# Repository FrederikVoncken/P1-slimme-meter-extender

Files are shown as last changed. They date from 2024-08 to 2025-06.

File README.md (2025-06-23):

# P1-slimme-meter-extender
Extending the range for a P1 slimmer meter connection and even making it possible to connect multiple receivers (having their own data enable).
***
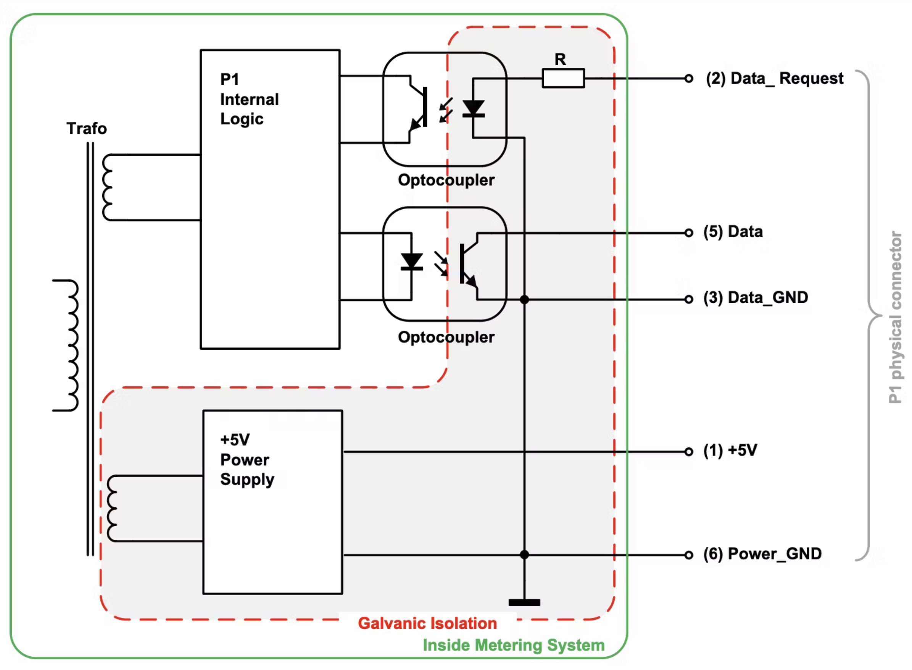
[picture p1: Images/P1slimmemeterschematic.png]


The inside of the P1 communication part.

See also 
[Wiki P1-poort](https://nl.wikipedia.org/wiki/P1-poort) and [DSMR P1 Companion Standard 5.0.2](https://www.netbeheernederland.nl/publicatie/dsmr-502-p1-companion-standard)
***
The schematic shows the extension of the Smartmeter P1 port to
* 2 (isolated) P1 outputs
* 2 P1 output extenders (RS485) to multiple meters
* Multiple options for isolation and power

See also the Kicad directory for the project and schematic
[Schematic](Kicad/P1SmartMeter.pdf)

The schematic can be extended to more P1 output or more P1 extenders

Images of the Main part, top and back

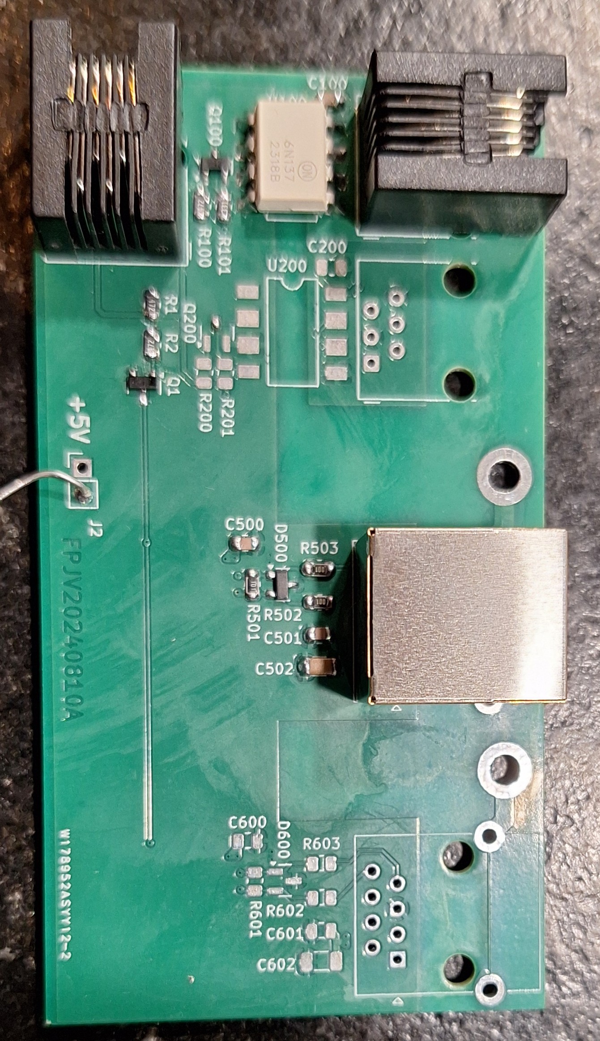
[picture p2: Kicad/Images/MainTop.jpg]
MainTop


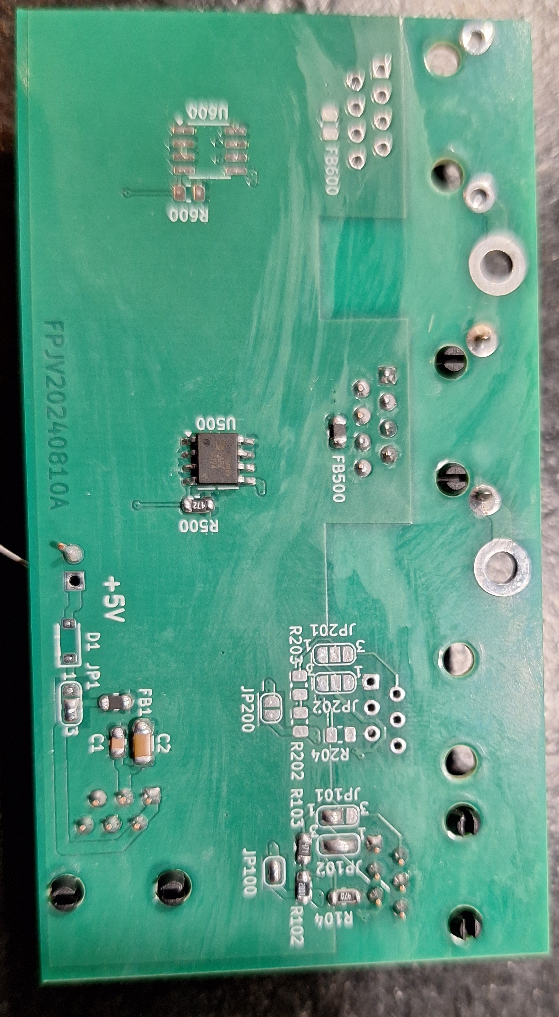
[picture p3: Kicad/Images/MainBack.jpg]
MainBack


Images of the extender receiving part, top and back

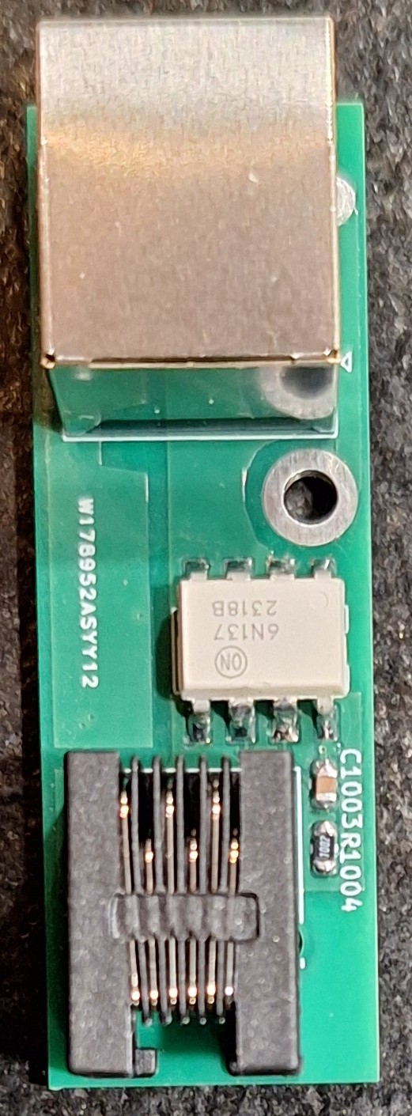
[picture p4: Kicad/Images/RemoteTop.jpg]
RemoteTop


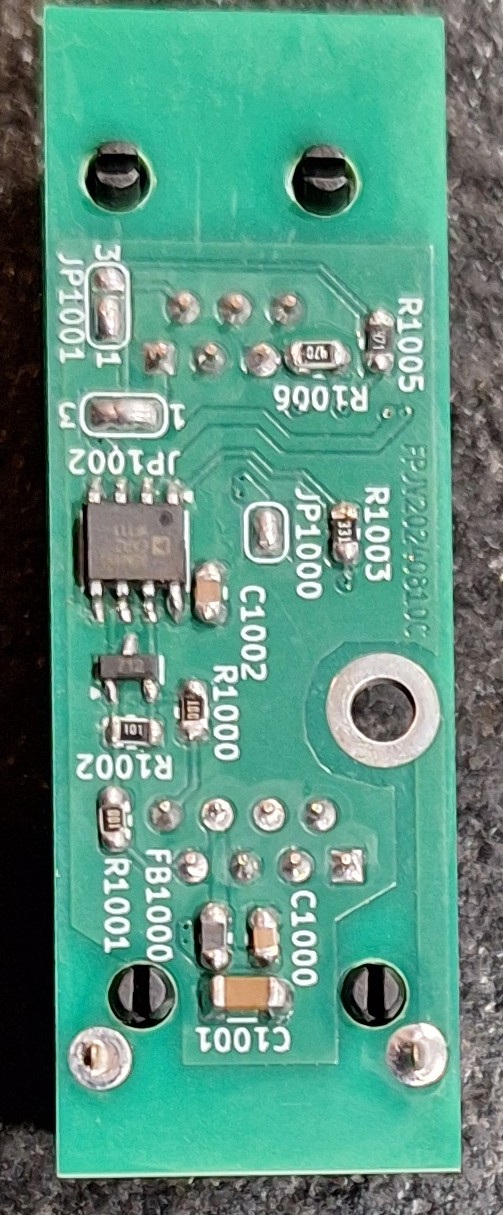
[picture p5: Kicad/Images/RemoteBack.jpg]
RemoteBack


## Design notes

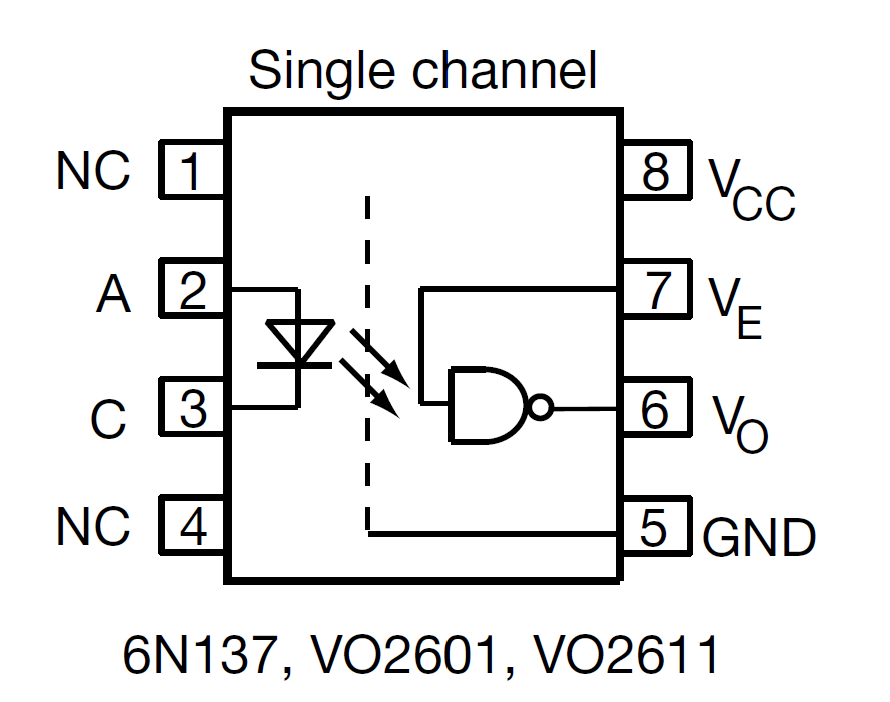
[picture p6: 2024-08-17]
Images/6n137.png

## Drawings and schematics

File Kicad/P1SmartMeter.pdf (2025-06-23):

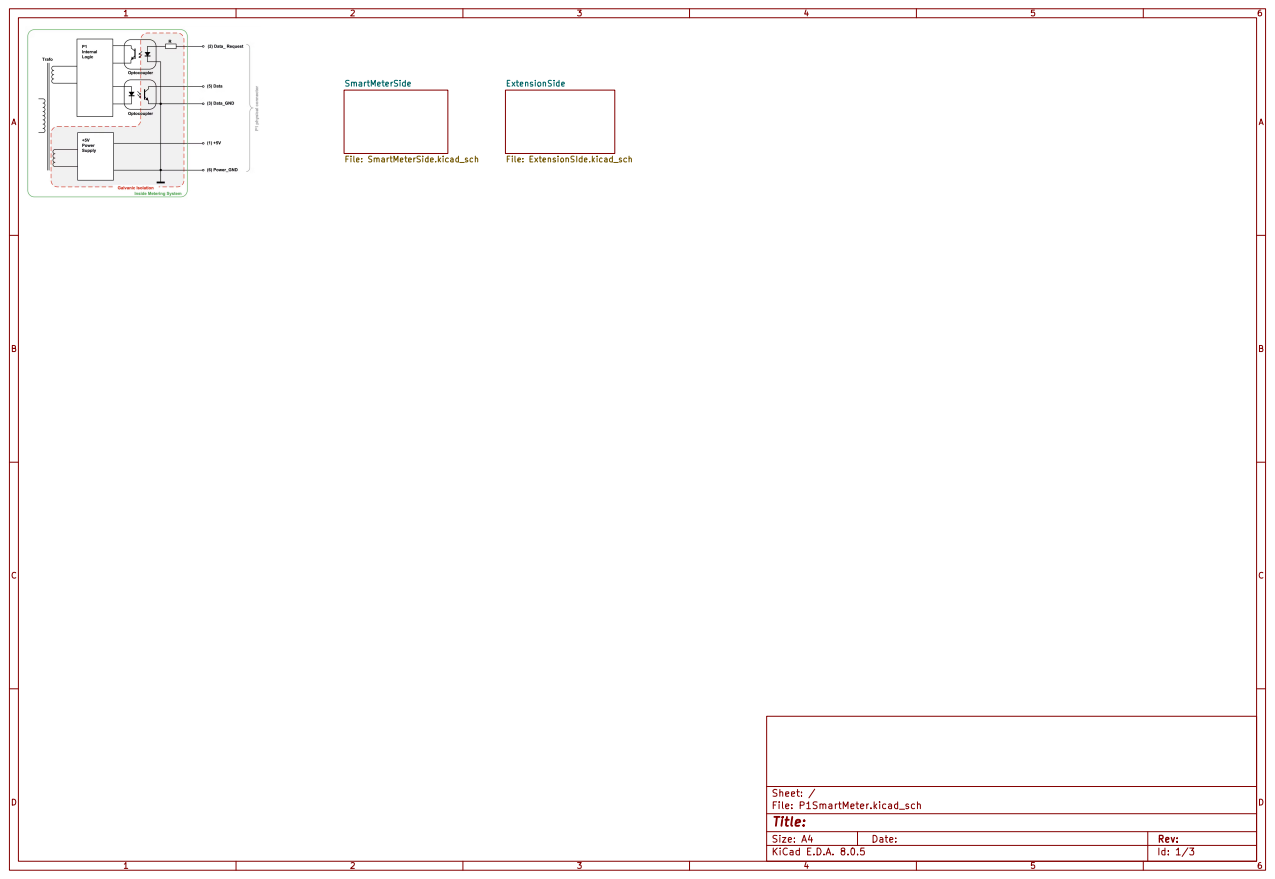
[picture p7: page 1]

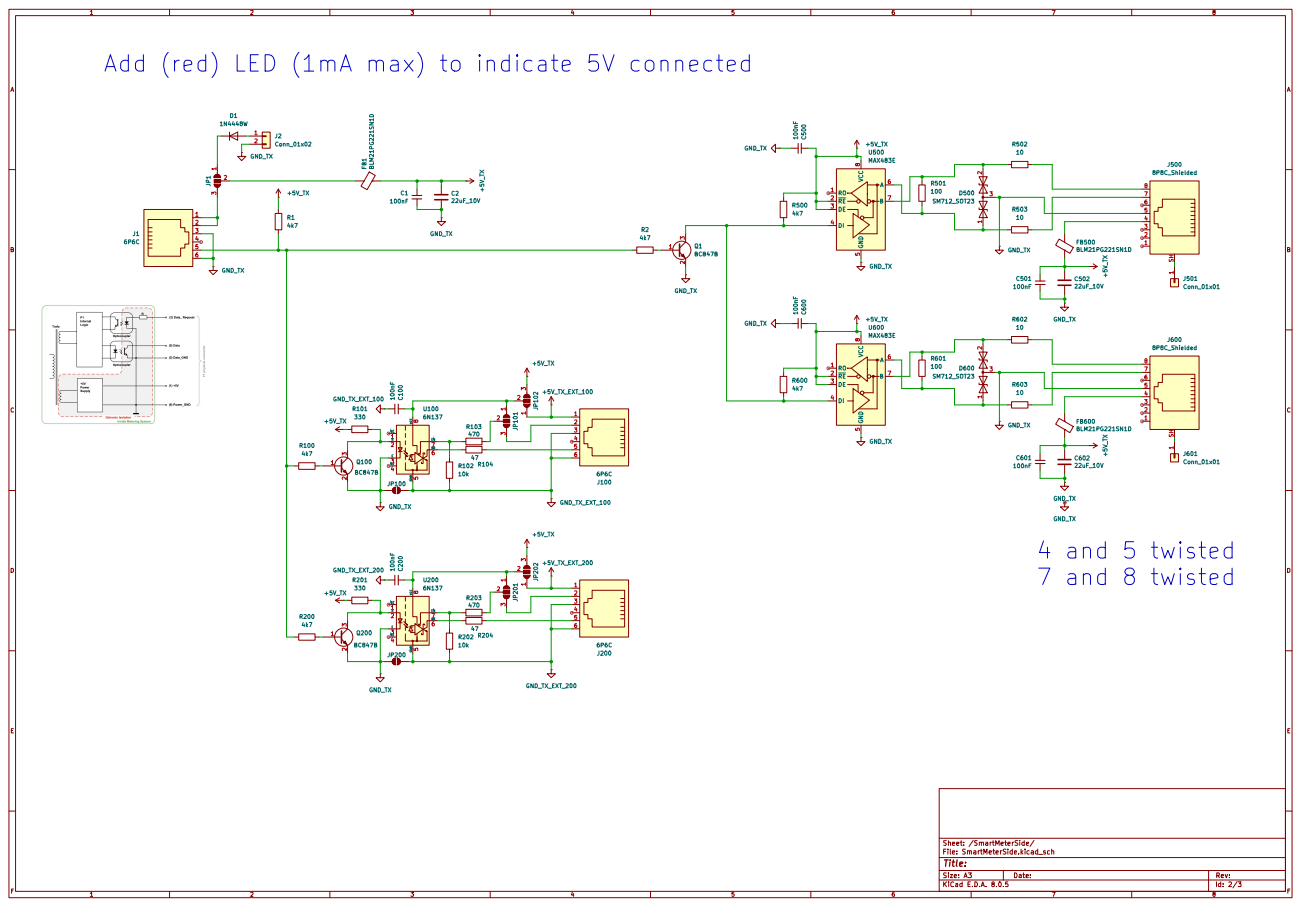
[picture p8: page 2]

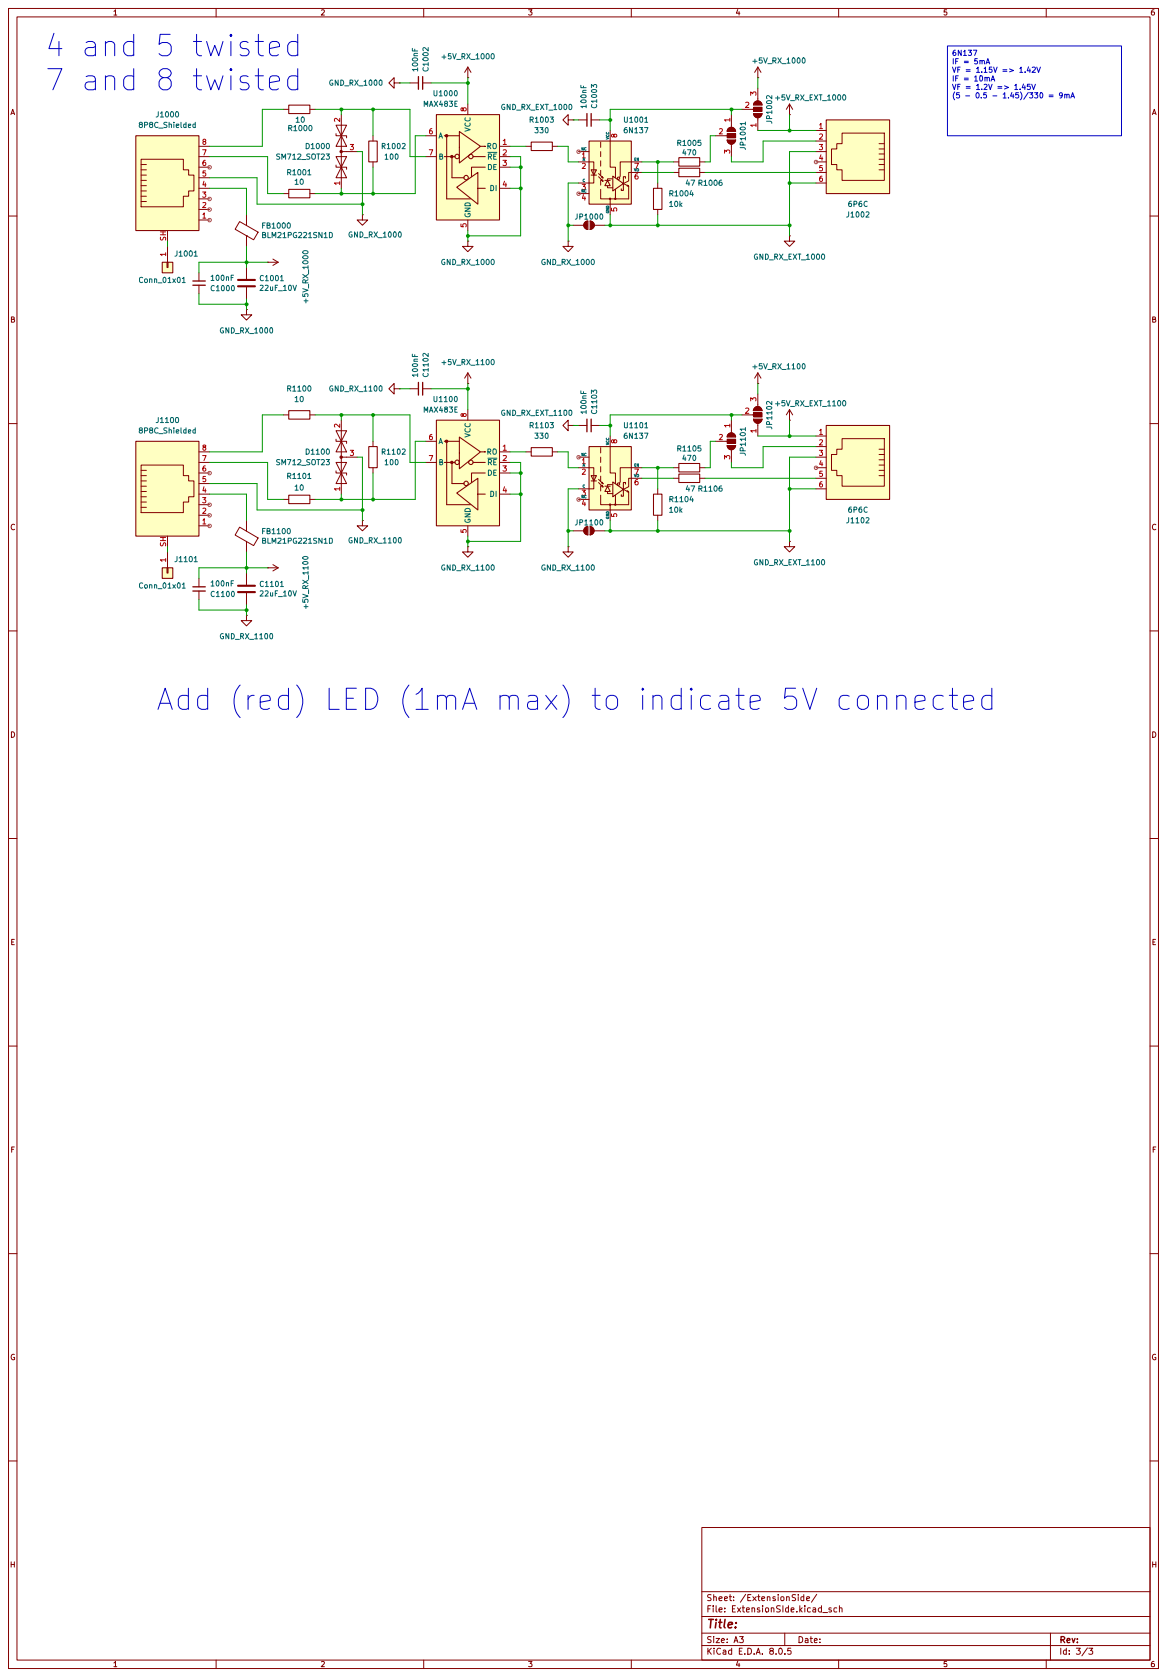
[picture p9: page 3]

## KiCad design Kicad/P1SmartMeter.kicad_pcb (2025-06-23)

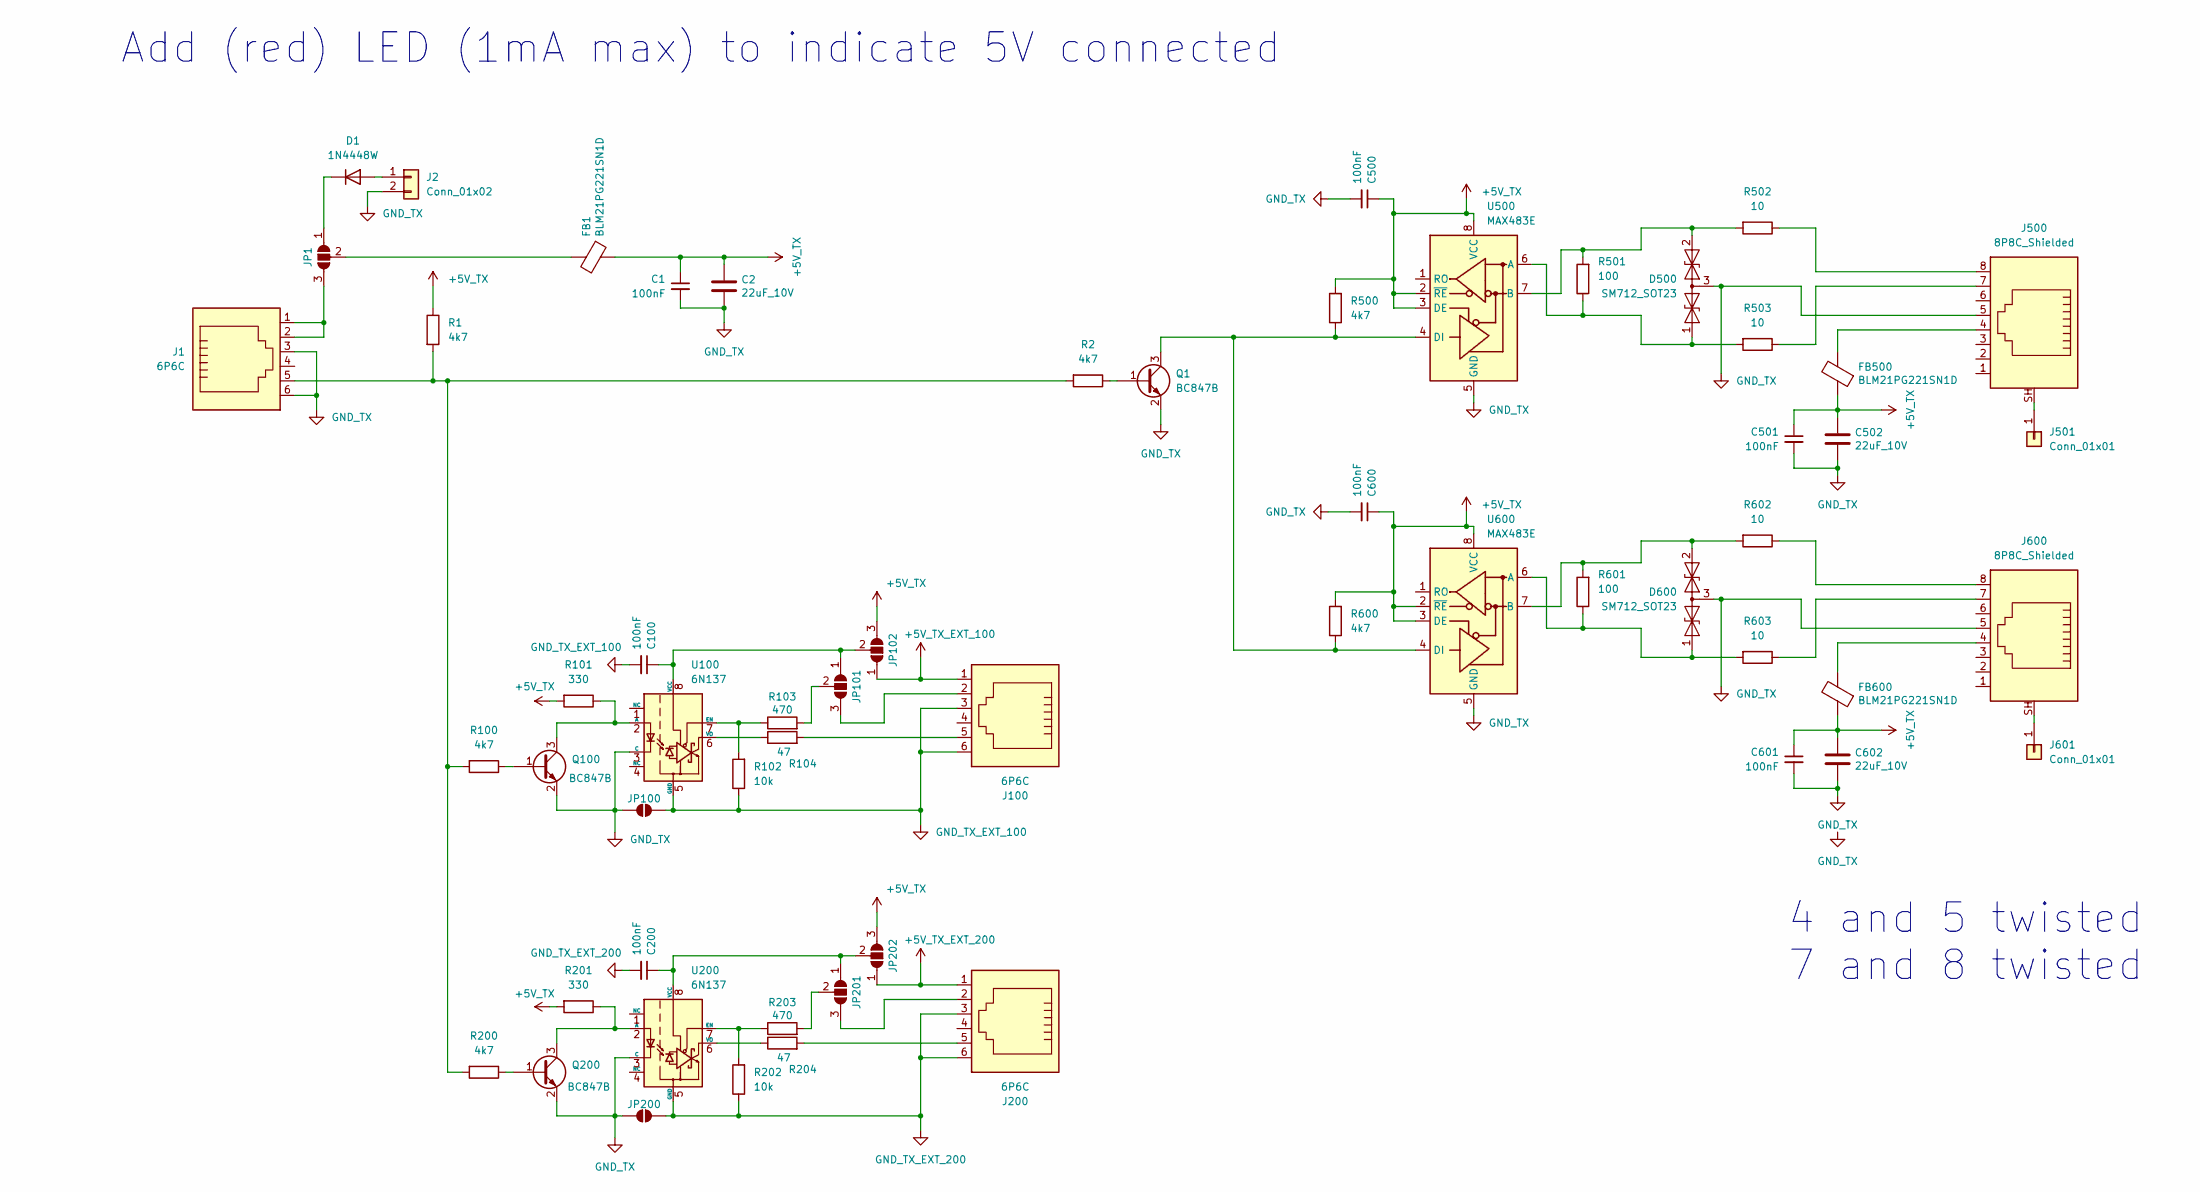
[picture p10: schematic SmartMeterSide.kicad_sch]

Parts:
C1, C100, C200, C500, C501, C600, C601: 100nF; C_0805_2012Metric
C2, C502, C602: 22uF_10V; C_1206_3216Metric
D1: 1N4448W; D_SOD-123
D500, D600: SM712_SOT23; SOT-23
FB1, FB500, FB600: BLM21PG221SN1D; R_0805_2012Metric
J1, J100, J200: 6P6C; RJ12_Amphenol_54601-x06_Horizontal
J2: Conn_01x02; PinHeader_1x02_P2.54mm_Vertical
J500, J600: 8P8C_Shielded; RJ45_Ninigi_GE
J501, J601: Conn_01x01; MountingHole_3.2mm_M3_DIN965_Pad_TopBottom
JP1, JP101, JP102, JP201, JP202: SolderJumper_3_Open; SolderJumper-3_P1.3mm_Open_RoundedPad1.0x1.5mm_NumberLabels
JP100, JP200: SolderJumper_2_Open; SolderJumper-2_P1.3mm_Open_RoundedPad1.0x1.5mm
Q1, Q100, Q200: BC847B; SOT-23
R1, R2, R100, R200, R500, R600: 4k7; R_0805_2012Metric
R101, R201: 330; R_0805_2012Metric
R102, R202: 10k; R_0805_2012Metric
R103, R203: 470; R_0805_2012Metric
R104, R204: 47; R_0805_2012Metric
R501, R601: 100; R_0805_2012Metric
R502, R503, R602, R603: 10; R_0805_2012Metric
U100, U200: 6N137; PowerIntegrations_SMD-8
U500, U600: MAX483E; SOIC-8_3.9x4.9mm_P1.27mm

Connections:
+5V_TX: C1.1, C2.1, C500.1, C501.1, C502.1, C600.1, C601.1, C602.1, FB1.1, FB500.1, FB600.1, JP102.3 (B), JP202.3 (B), R1.1, R101.2, R201.2, R500.2, R600.2, U500.2 (~RE), U500.3 (DE), U500.8 (VCC), U600.2 (~RE), U600.3 (DE), U600.8 (VCC)
+5V_TX_EXT_100: J100.1, JP102.1 (A)
+5V_TX_EXT_200: J200.1, JP202.1 (A)
GND_TX: C1.2, C2.2, C500.2, C501.2, C502.2, C600.2, C601.2, C602.2, D500.3 (common), D600.3 (common), J1.3, J1.6, J2.2, J500.5, J600.5, JP100.1 (A), JP200.1 (A), Q1.2 (E), Q100.2 (E), Q200.2 (E), U100.3 (C), U200.3 (C), U500.5 (GND), U600.5 (GND)
GND_TX_EXT_100: C100.2, J100.3, J100.6, JP100.2 (B), R102.1, U100.5 (GND)
GND_TX_EXT_200: C200.2, J200.3, J200.6, JP200.2 (B), R202.1, U200.5 (GND)
unnamed: D1.2 (A), J2.1
unnamed: D1.1 (K), JP1.1 (A)
unnamed: D500.1 (A1), R501.1, R503.2, U500.6 (A)
unnamed: D500.2 (A2), R501.2, R502.2, U500.7 (B)
unnamed: D600.1 (A1), R601.1, R603.2, U600.6 (A)
unnamed: D600.2 (A2), R601.2, R602.2, U600.7 (B)
unnamed: FB500.2, J500.4
unnamed: FB600.2, J600.4
unnamed: J1.5, R1.2, R2.2, R100.2, R200.2
unnamed: J100.5, R104.2
unnamed: J200.5, R204.2
unnamed: J500.7, R503.1
unnamed: J500.8, R502.1
unnamed: J500.SH, J501.1
unnamed: J600.7, R603.1
unnamed: J600.8, R602.1
unnamed: J600.SH, J601.1
unnamed: J1.1, J1.2, JP1.3 (B)
unnamed: FB1.2, JP1.2 (C)
unnamed: C100.1, JP101.1 (A), JP102.2 (C), U100.8 (VCC)
unnamed: J100.2, JP101.3 (B)
unnamed: JP101.2 (C), R103.2
unnamed: C200.1, JP201.1 (A), JP202.2 (C), U200.8 (VCC)
unnamed: J200.2, JP201.3 (B)
unnamed: JP201.2 (C), R203.2
unnamed: Q1.1 (B), R2.1
unnamed: Q1.3 (C), R500.1, R600.1, U500.4 (DI), U600.4 (DI)
unnamed: Q100.1 (B), R100.1
unnamed: Q100.3 (C), R101.1, U100.2 (A)
unnamed: Q200.1 (B), R200.1
unnamed: Q200.3 (C), R201.1, U200.2 (A)
unnamed: R102.2, R103.1, U100.7 (EN)
unnamed: R104.1, U100.6 (VO)
unnamed: R202.2, R203.1, U200.7 (EN)
unnamed: R204.1, U200.6 (VO)

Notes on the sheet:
Add (red) LED (1mA max) to indicate 5V connected
4 and 5 twisted 7 and 8 twisted

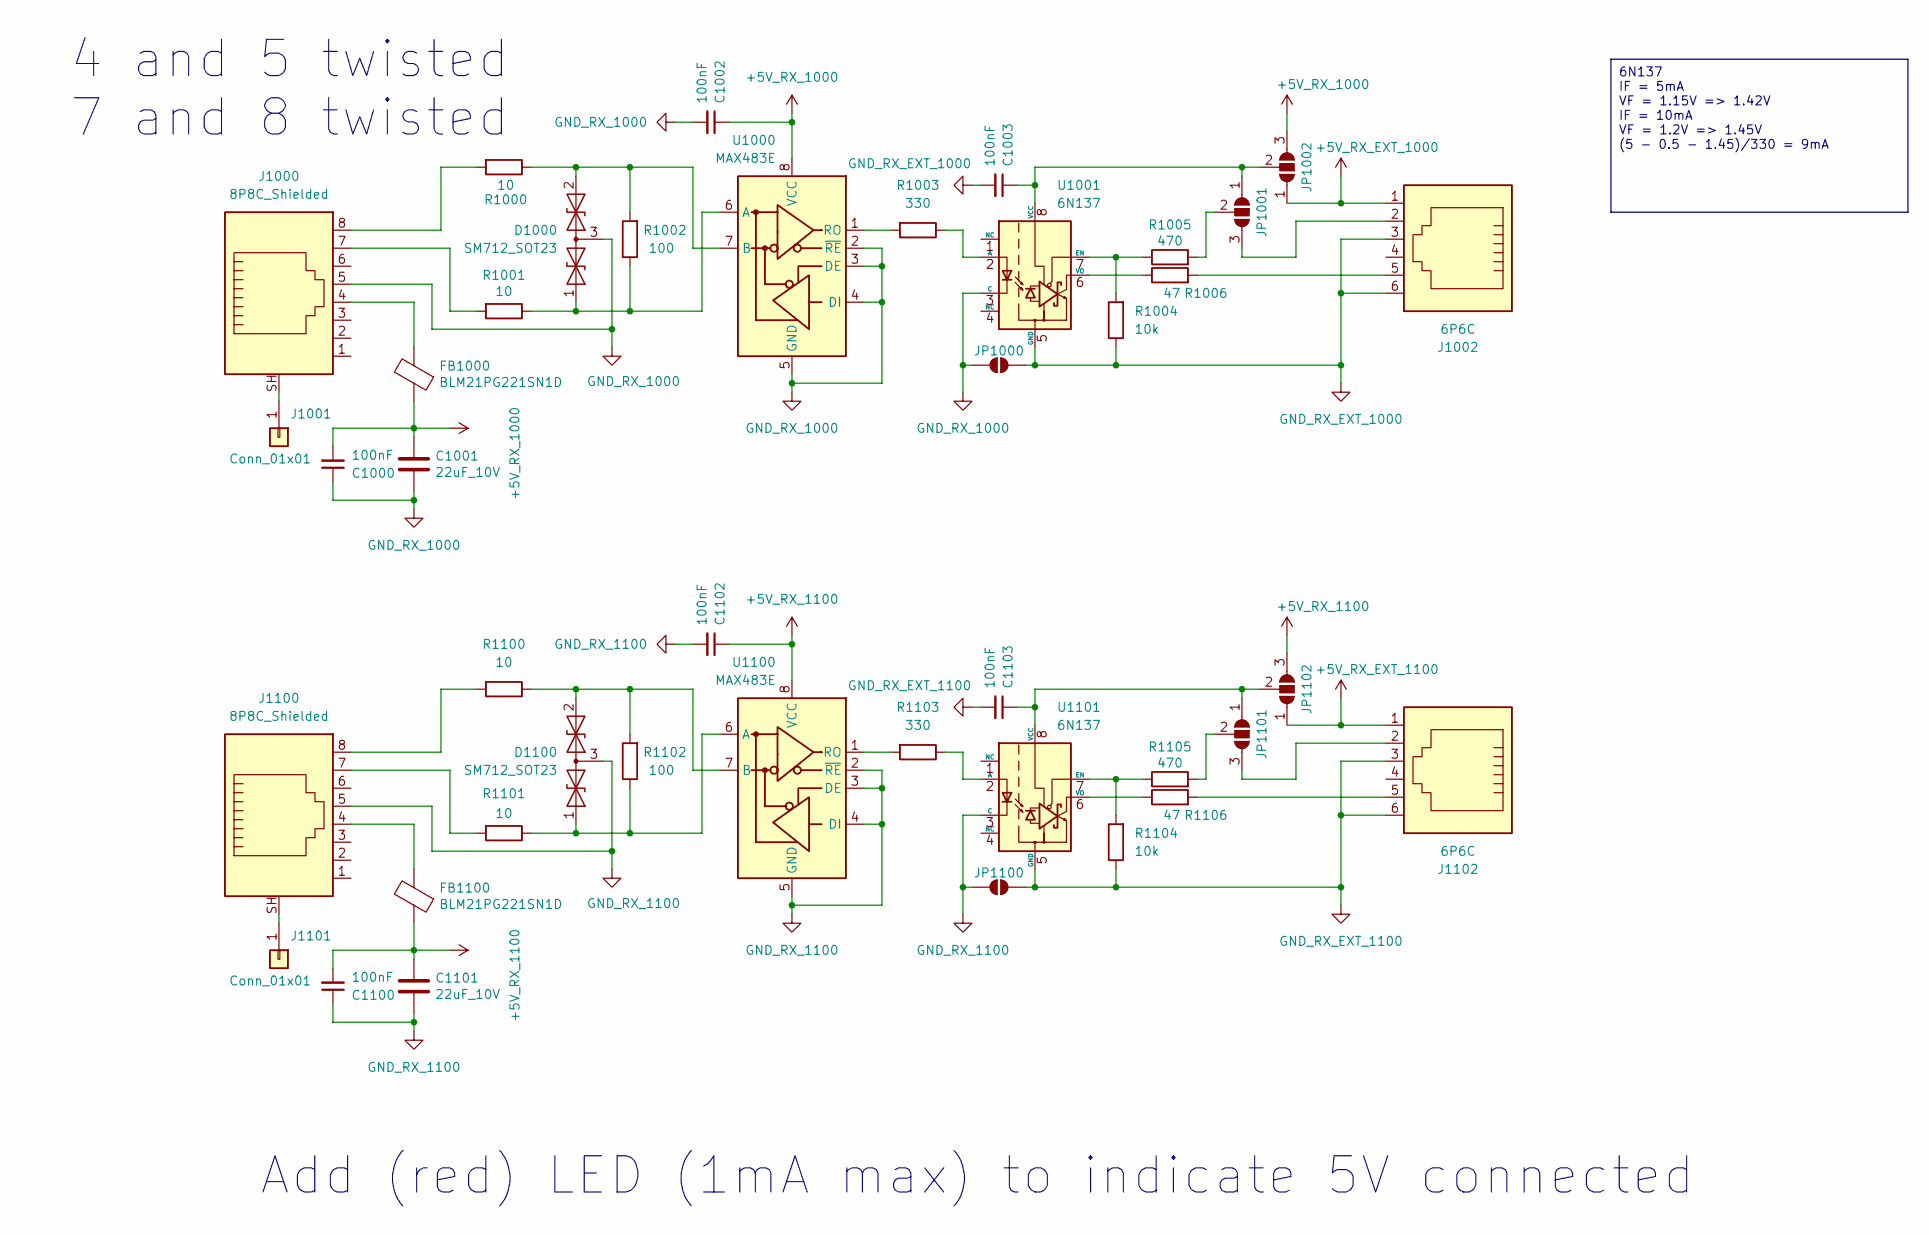
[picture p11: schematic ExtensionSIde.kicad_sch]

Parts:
C1000, C1002, C1003, C1100, C1102, C1103: 100nF; C_0805_2012Metric
C1001, C1101: 22uF_10V; C_1206_3216Metric
D1000, D1100: SM712_SOT23; SOT-23
FB1000, FB1100: BLM21PG221SN1D; R_0805_2012Metric
J1000, J1100: 8P8C_Shielded; RJ45_Ninigi_GE
J1001, J1101: Conn_01x01; MountingHole_3.2mm_M3_DIN965_Pad_TopBottom
J1002, J1102: 6P6C; RJ12_Amphenol_54601-x06_Horizontal
JP1000, JP1100: SolderJumper_2_Open; SolderJumper-2_P1.3mm_Open_RoundedPad1.0x1.5mm
JP1001, JP1002, JP1101, JP1102: SolderJumper_3_Open; SolderJumper-3_P1.3mm_Open_RoundedPad1.0x1.5mm_NumberLabels
R1000, R1001, R1100, R1101: 10; R_0805_2012Metric
R1002, R1102: 100; R_0805_2012Metric
R1003, R1103: 330; R_0805_2012Metric
R1004, R1104: 10k; R_0805_2012Metric
R1005, R1105: 470; R_0805_2012Metric
R1006, R1106: 47; R_0805_2012Metric
U1000, U1100: MAX483E; SOIC-8_3.9x4.9mm_P1.27mm
U1001, U1101: 6N137; PowerIntegrations_SMD-8

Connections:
+5V_RX_1000: C1000.2, C1001.1, C1002.1, FB1000.1, JP1002.3 (B), U1000.8 (VCC)
+5V_RX_1100: C1100.2, C1101.1, C1102.1, FB1100.1, JP1102.3 (B), U1100.8 (VCC)
+5V_RX_EXT_1000: J1002.1, JP1002.1 (A)
+5V_RX_EXT_1100: J1102.1, JP1102.1 (A)
GND_RX_1000: C1000.1, C1001.2, C1002.2, D1000.3 (common), J1000.5, JP1000.1 (A), U1000.2 (~RE), U1000.3 (DE), U1000.4 (DI), U1000.5 (GND), U1001.3 (C)
GND_RX_1100: C1100.1, C1101.2, C1102.2, D1100.3 (common), J1100.5, JP1100.1 (A), U1100.2 (~RE), U1100.3 (DE), U1100.4 (DI), U1100.5 (GND), U1101.3 (C)
GND_RX_EXT_1000: C1003.2, J1002.3, J1002.6, JP1000.2 (B), R1004.1, U1001.5 (GND)
GND_RX_EXT_1100: C1103.2, J1102.3, J1102.6, JP1100.2 (B), R1104.1, U1101.5 (GND)
unnamed: D1000.1 (A1), R1001.1, R1002.1, U1000.6 (A)
unnamed: D1000.2 (A2), R1000.1, R1002.2, U1000.7 (B)
unnamed: D1100.1 (A1), R1101.1, R1102.1, U1100.6 (A)
unnamed: D1100.2 (A2), R1100.1, R1102.2, U1100.7 (B)
unnamed: FB1000.2, J1000.4
unnamed: FB1100.2, J1100.4
unnamed: J1000.7, R1001.2
unnamed: J1000.8, R1000.2
unnamed: J1000.SH, J1001.1
unnamed: J1002.5, R1006.2
unnamed: J1100.7, R1101.2
unnamed: J1100.8, R1100.2
unnamed: J1100.SH, J1101.1
unnamed: J1102.5, R1106.2
unnamed: C1003.1, JP1001.1 (A), JP1002.2 (C), U1001.8 (VCC)
unnamed: J1002.2, JP1001.3 (B)
unnamed: JP1001.2 (C), R1005.2
unnamed: C1103.1, JP1101.1 (A), JP1102.2 (C), U1101.8 (VCC)
unnamed: J1102.2, JP1101.3 (B)
unnamed: JP1101.2 (C), R1105.2
unnamed: R1003.2, U1000.1 (RO)
unnamed: R1003.1, U1001.2 (A)
unnamed: R1004.2, R1005.1, U1001.7 (EN)
unnamed: R1006.1, U1001.6 (VO)
unnamed: R1103.2, U1100.1 (RO)
unnamed: R1103.1, U1101.2 (A)
unnamed: R1104.2, R1105.1, U1101.7 (EN)
unnamed: R1106.1, U1101.6 (VO)

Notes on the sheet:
6N137 IF = 5mA VF = 1.15V => 1.42V IF = 10mA VF = 1.2V => 1.45V (5 - 0.5 - 1.45)/330 = 9mA
4 and 5 twisted 7 and 8 twisted
Add (red) LED (1mA max) to indicate 5V connected

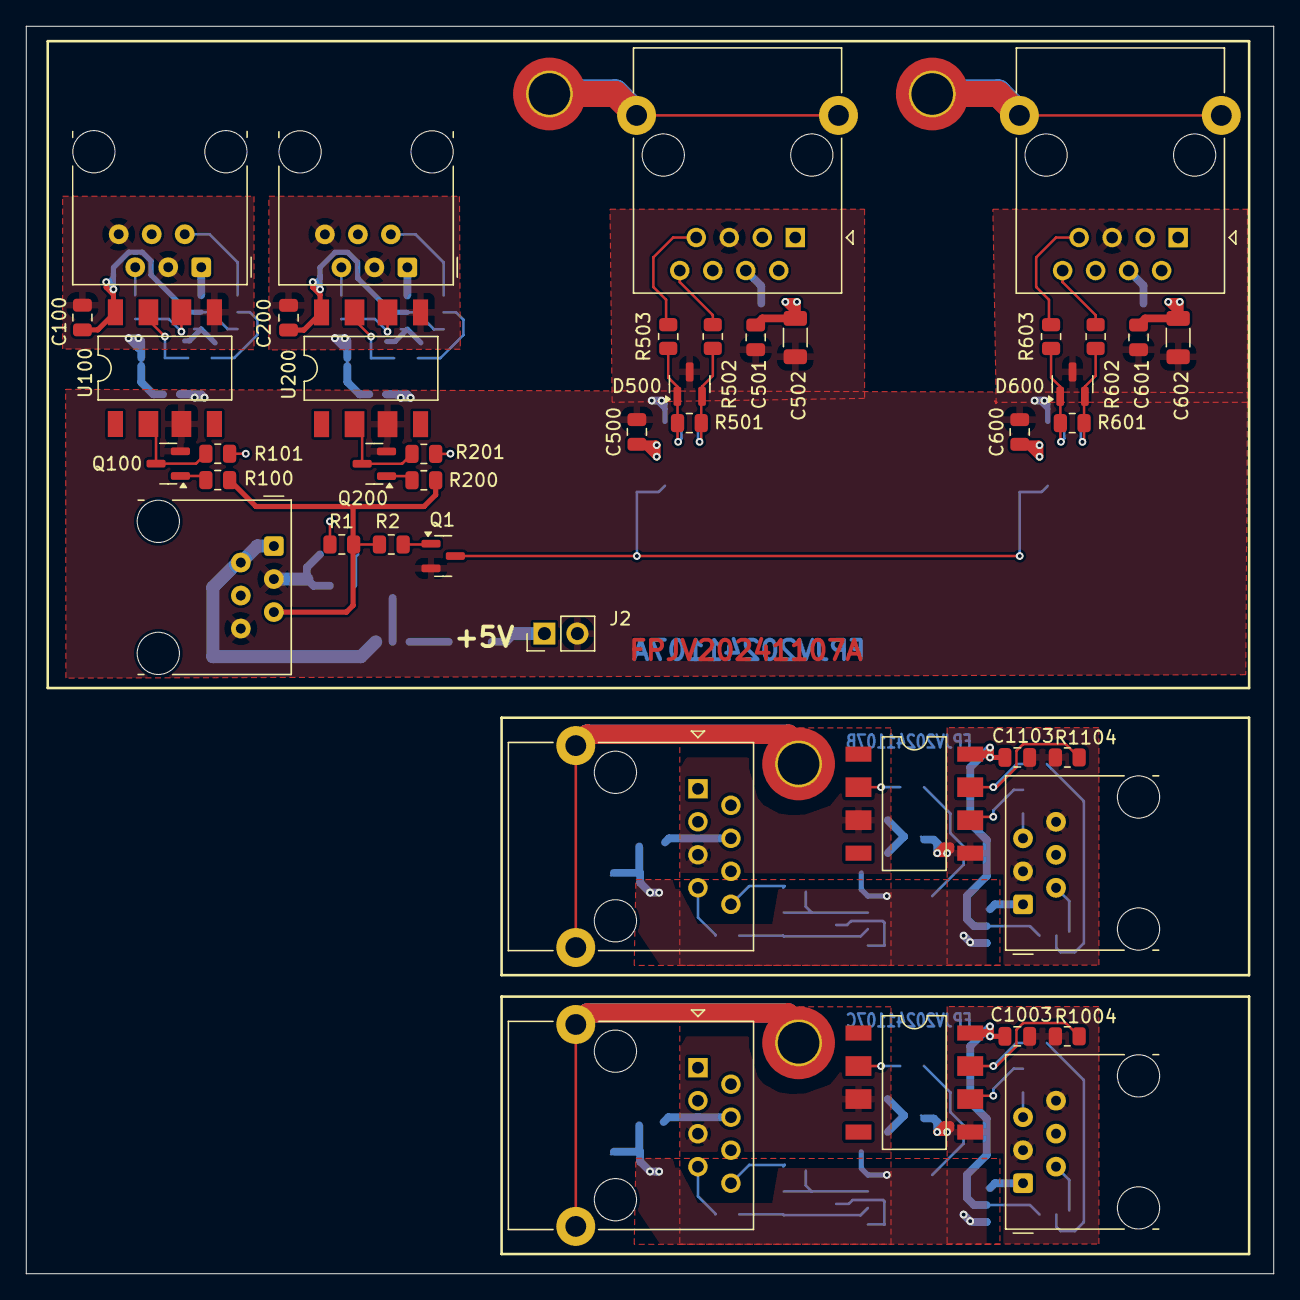
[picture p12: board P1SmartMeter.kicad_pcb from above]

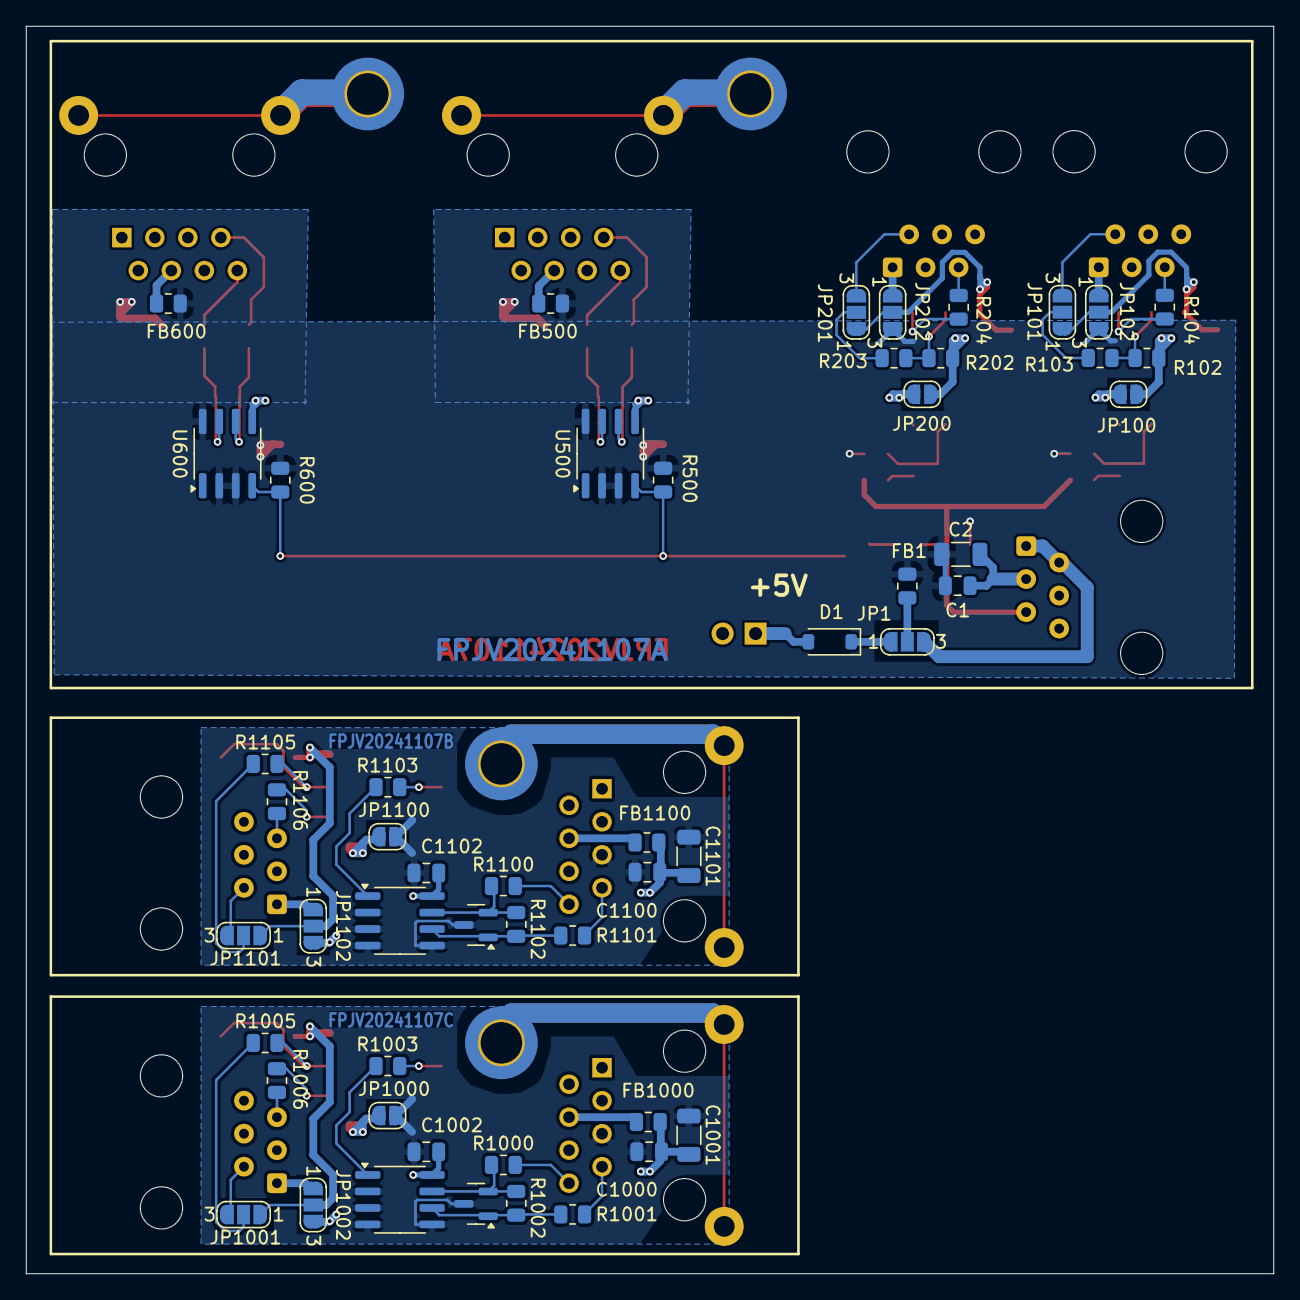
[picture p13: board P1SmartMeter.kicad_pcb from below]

Board: 2 copper layers, 96.0 x 96.0 mm, 100 parts (53 on the bottom side), 77 nets.
